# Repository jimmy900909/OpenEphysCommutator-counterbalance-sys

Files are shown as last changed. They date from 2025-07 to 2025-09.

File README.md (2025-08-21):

This is a wireless counterbalance system that can adjust the length of the cable automatically for OpenEphys commutator while conducting freely moving animal experiment  

#closed-loop Automatic Counterbalance animal experiment system 

#tension-free and biting-prevention for cable in the freely moving animal experiment

The toggling and dragging can seriously cause the artifacts to signal when doing a cable-connected behavior experiment on an awake and freely-moving animal. The automatic rotation commutator is widely used in labs and commercialized, however, to adjust the length of the cable is always depends on manual holding or passive counterbalance sys. As the hanged part would be bited by animal and the tension can constraint the movement, a active counterbalance system is needed for such animal experiment.

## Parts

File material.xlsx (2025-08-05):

Material | model number | amount | source | note
MCU | Arduino Nano | 1
Weight sensor | HX711 | 1 | https://www.amazon.de/Geekstory-Amplifier-Precision-Converter-Raspberry/dp/B0BVBBZG2V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
Loadcell | 100g | 1 | https://www.amazon.de/0%E2%80%91100G-Parallel-Electronic-Weighing-Precision/dp/B0BZ62BRWK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 | 300g or 500g can be alternative but the installation drill holes on the 3D print structure needs to be modified
Motor Driver | DRV8833 | 1 | https://www.amazon.de/-/en/Heevhas-DRV8833-Module-Controller-Printer/dp/B0DQZGP1J4
capacitor | 470muF | 1
capacitor | 100muF | 1
Gear Motor | FIT0483 | 1
Battery set | 6V | 1 |  | For MCU also Motor

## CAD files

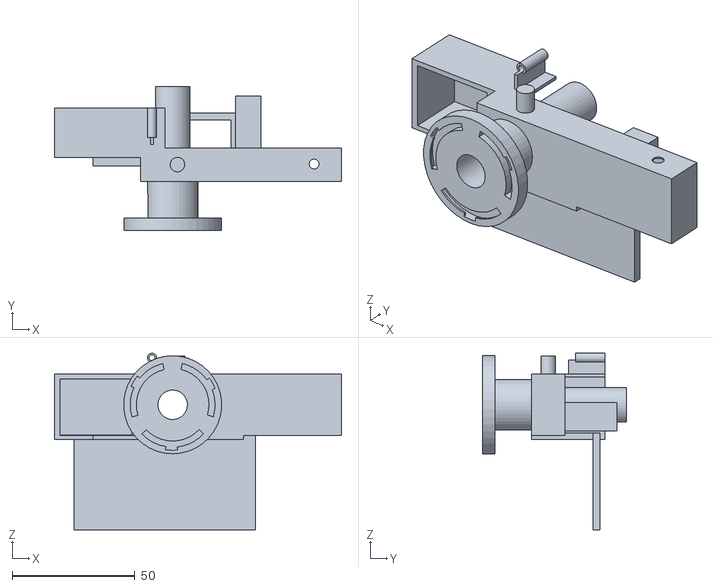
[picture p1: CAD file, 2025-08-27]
counterbalance/openephyscommutator/Holder_evas.STL
117.1 x 58.7 x 72.0

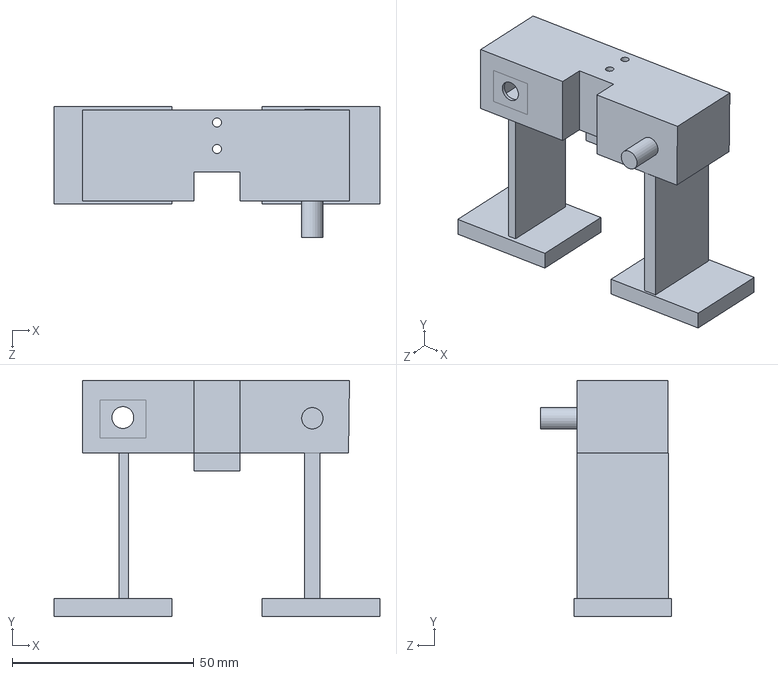
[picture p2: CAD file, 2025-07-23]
counterbalance/testing/TESTING frame.SLDPRT
89.6 x 65.0 x 35.9 mm

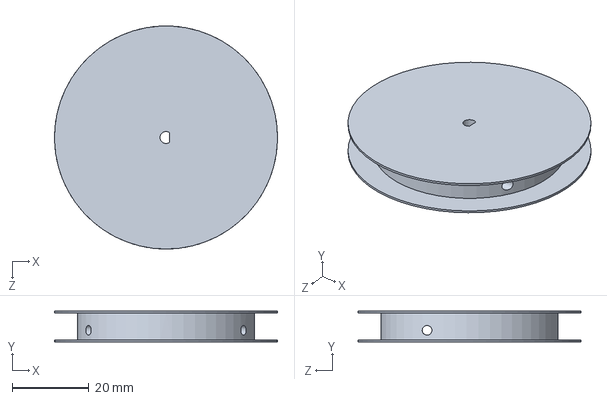
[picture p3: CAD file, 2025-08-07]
counterbalance/openephyscommutator/pulley_motor.SLDPRT
58.0 x 8.00 x 58.0 mm

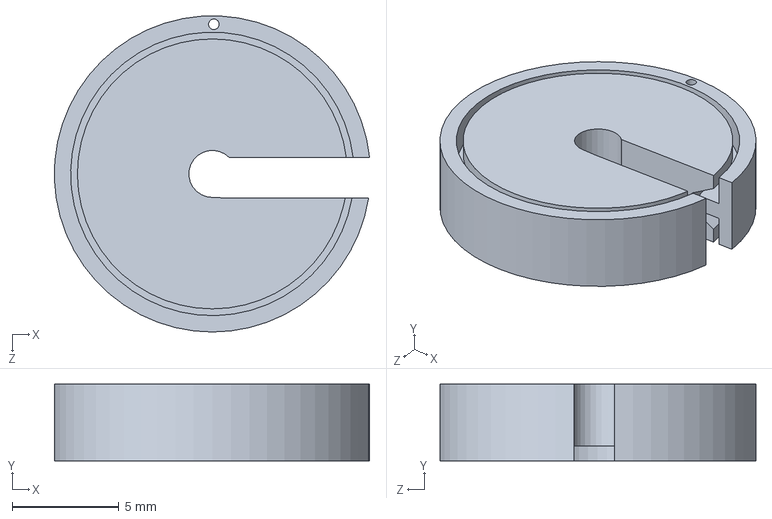
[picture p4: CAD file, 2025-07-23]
counterbalance/testing/bearing.SLDPRT
14.8 x 3.60 x 14.8 mm

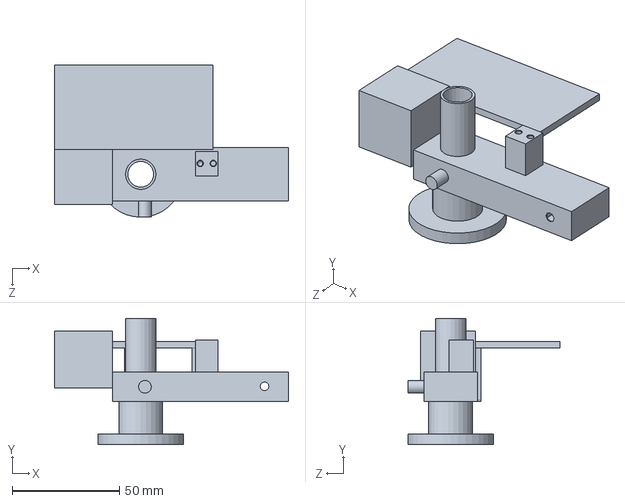
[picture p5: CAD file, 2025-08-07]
counterbalance/openephyscommutator/Holder_OE_v2.SLDPRT
109.1 x 58.7 x 71.0 mm

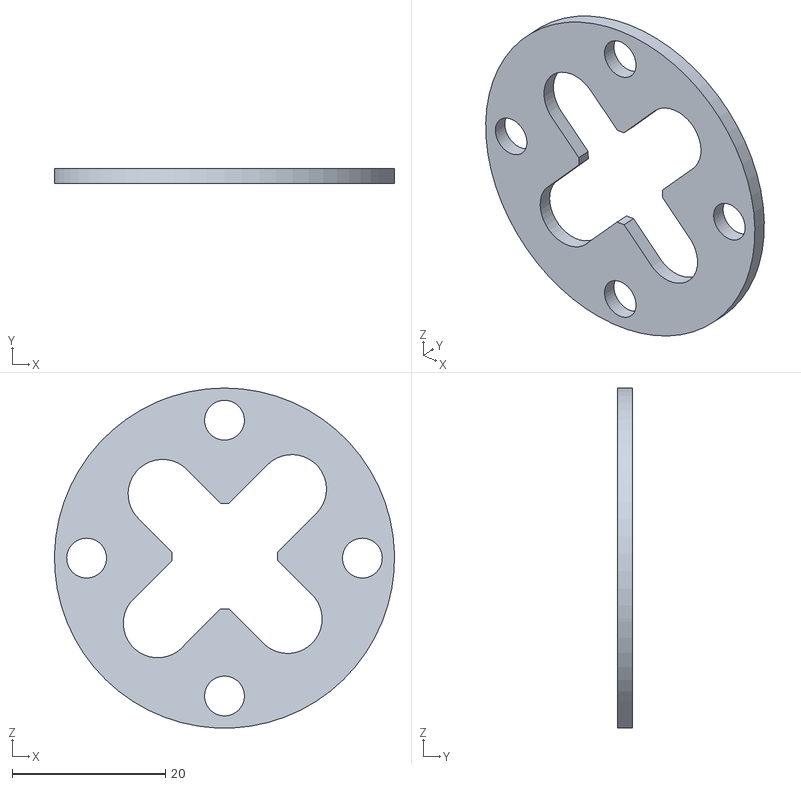
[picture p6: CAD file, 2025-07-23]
counterbalance/testing/attachplatform.STL
44.4 x 2.00 x 44.4

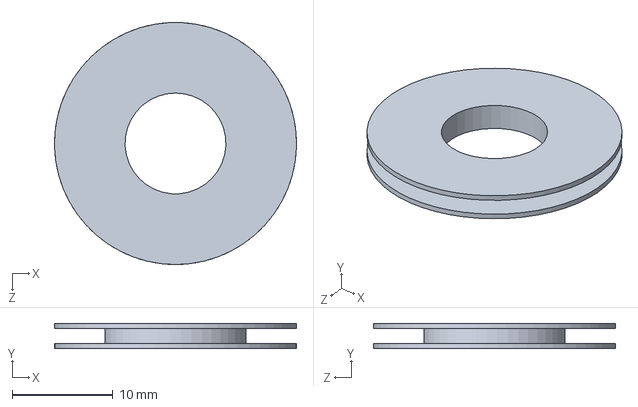
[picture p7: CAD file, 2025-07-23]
counterbalance/openephyscommutator/pulley_fixed.SLDPRT
24.0 x 2.50 x 24.0 mm

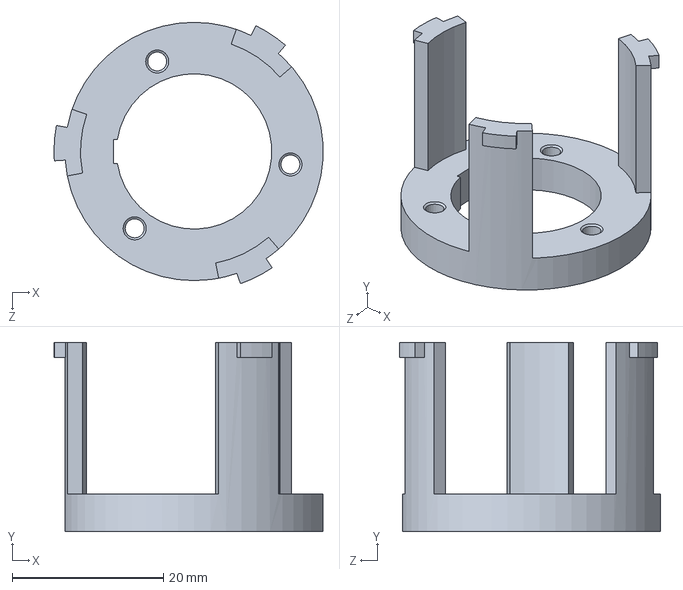
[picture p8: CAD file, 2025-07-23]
counterbalance/openephyscommutator/adaptor_OE.SLDPRT
35.5 x 25.0 x 34.5 mm

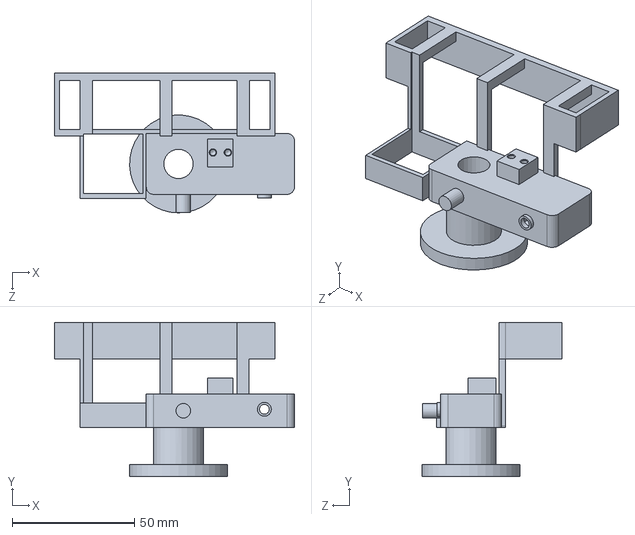
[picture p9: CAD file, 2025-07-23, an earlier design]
counterbalance/openephyscommutator/Holder_OE.SLDPRT
98.1 x 63.0 x 57.1 mm

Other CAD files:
counterbalance/openephyscommutator/Holder_OE.STL
counterbalance/openephyscommutator/Holder_OE_v2.STL
counterbalance/openephyscommutator/adaptor_OE.STL
counterbalance/openephyscommutator/pulley_fixed.STL
counterbalance/openephyscommutator/pulley_motor.STL
counterbalance/testing/TESTING frame.STL
counterbalance/testing/bearing.STL

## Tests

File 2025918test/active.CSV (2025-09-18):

time | T_fast_g | T_slow_g | v_line_mps | leash_m | pwm_state | enc_count | dTdt_gps
1758187201.288 | 0.0000 | 0.0000 | 0.000000 | 0.0000 | 60 | 0 | 0.00
1758187201.308 | 0.0000 | 0.0000 | 0.000000 | 0.0002 | 70 | 2 | 0.00
1758187201.328 | 0.0000 | 0.0000 | 0.088051 | 0.0010 | 70 | 11 | 0.00
1758187201.348 | 0.0000 | 0.0000 | 0.000000 | 0.0019 | 70 | 23 | 0.00
1758187201.368 | 0.0000 | 0.0000 | 0.088051 | 0.0033 | 70 | 38 | 0.00
1758187201.388 | -0.0040 | -0.0013 | 0.000000 | 0.0048 | 70 | 56 | 0.00
1758187201.408 | -0.0040 | -0.0013 | 0.088051 | 0.0064 | 70 | 73 | 0.00
1758187201.428 | -0.0040 | -0.0013 | 0.088051 | 0.0081 | 70 | 92 | 0.00
1758187201.448 | -0.0040 | -0.0013 | 0.088051 | 0.0097 | 70 | 110 | 0.00
1758187201.468 | -0.0040 | -0.0013 | 0.088051 | 0.0113 | 70 | 129 | 0.00
1758187201.488 | -0.0044 | -0.0021 | 0.088051 | 0.0129 | 70 | 146 | -0.00
1758187201.508 | -0.0044 | -0.0021 | 0.088051 | 0.0144 | 70 | 164 | -0.00
1758187201.528 | -0.0044 | -0.0021 | 0.088051 | 0.0158 | 70 | 181 | -0.00
1758187201.548 | -0.0044 | -0.0021 | 0.088051 | 0.0173 | 70 | 197 | -0.00
1758187201.568 | -0.0044 | -0.0021 | 0.088051 | 0.0188 | 70 | 213 | -0.00
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

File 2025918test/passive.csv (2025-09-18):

Timestamp | RawReading | Weight_g
2025-09-18 11:57:35.753 | 41840 | 0.00
2025-09-18 11:57:35.755 | 41747 | -0.01
2025-09-18 11:57:35.755 | 41789 | -0.00
2025-09-18 11:57:35.759 | 41779 | -0.01
2025-09-18 11:57:35.764 | 41789 | 0.00
2025-09-18 11:57:36.068 | 41740 | -0.02
2025-09-18 11:57:36.847 | 41819 | -0.00
2025-09-18 11:57:37.627 | 41724 | 0.00
2025-09-18 11:57:38.409 | 41811 | -0.01
2025-09-18 11:57:39.189 | 41776 | -0.00
2025-09-18 11:57:39.969 | 62621 | 6.28
2025-09-18 11:57:40.749 | 104551 | 15.10
2025-09-18 11:57:41.529 | 106632 | 17.36
2025-09-18 11:57:42.308 | 122982 | 19.24
2025-09-18 11:57:43.088 | 124694 | 19.62
2025-09-18 11:57:43.868 | 172800 | 31.02
2025-09-18 11:57:44.648 | 162331 | 28.33
2025-09-18 11:57:45.432 | 157970 | 27.94
2025-09-18 11:57:46.211 | 177289 | 31.47
2025-09-18 11:57:46.992 | 176594 | 32.62
2025-09-18 11:57:47.772 | 167508 | 27.82
2025-09-18 11:57:48.552 | 147660 | 23.36
2025-09-18 11:57:49.333 | 177326 | 32.94
2025-09-18 11:57:50.112 | 170128 | 30.60
2025-09-18 11:57:50.891 | 170732 | 31.23
2025-09-18 11:57:51.672 | 175176 | 32.32
2025-09-18 11:57:52.454 | 238303 | 42.79
2025-09-18 11:57:53.231 | 160631 | 23.22
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

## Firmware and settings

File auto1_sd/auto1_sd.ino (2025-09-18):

#include "HX711.h"
#include <SPI.h>
#include <SD.h>

// ---------------- Pins ----------------
// HX711
#define DOUT 4
#define CLK  5
// Motor
#define AIN1 6
#define AIN2 9
// Encoder pins
#define ENCODER_A 2
#define ENCODER_B 3
// SD module
const int SD_CS = 10;   // CS pin of SD card

// ---------------- HX711 ----------------
HX711 scale;
float calibration_factor = 4180;  // g
const float HX_RATE_HZ = 80.0f;   // soldering modified
unsigned long last_hx_ms = 0;
bool hx_updated = false;
bool have_prev_T = false;

// ---------------- Encoder → v_line ----------------
const float COUNTS_PER_METER = 11357.0f;
volatile long encoderCount = 0;
long lastCount = 0;
unsigned long lastVtMs = 0;
float v_line = 0.0f;         
float leash_len_m = 0.0f;

// ---------------- Motor / PWM ----------------
const int remotorSpeed = 65;   // retract PWM (upper bound)
int pwm_state = 0;
const int PWM_STEP_OUT = 120;   
const int PWM_STEP_IN  = 30;   
// retracting PWM
const int   BASE_RETRACT_PWM     = 45;     // base PWM
const int   MAX_RETRACT_PWM      = 70;     // Maximum PWM
const int   MIN_RETRACT_PWM      = 40;     // Minimum
const float KP_RETRACT_PWM_PER_G = 3.0f;   // gain per gram lower than lowerlimit

// loosening PWM
const int   BASE_PAYOUT_PWM   = 70;
const int   MAX_PAYOUT_PWM    = 190;
const float KP_PWM_PER_G      = 4.0f; // gain per gram after surpass upperlimit

// ---------------- Burst（instantpayout for strong drag） ----------------
const int BURST_PWM = 230;                     
const unsigned long BURST_MS = 150;            
unsigned long burst_until_ms = 0;

// ---------------- Landing impact give-way ----------------
const float IMPACT_DTDT_GPS = 90.0f;            
const float IMPACT_NEAR_UPPER_G = 0.8f;         
const unsigned long IMPACT_COAST_MS = 120;      
const int IMPACT_PAYOUT_PWM = 70;               
unsigned long impact_until_ms = 0;              

// No retracting after burst
const unsigned long POST_BURST_NO_RETRACT_MS = 600;     
unsigned long no_retract_until_ms = 0;

// ---------------- Smoothen tension ----------------
float T_fast_g = 0.0f;                
float T_slow_g = 0.0f;                
const float T_ALPHA_FAST = 0.8f;      // ★ bigger to be more sensitive 
const float T_ALPHA_SLOW = 0.25f;

// ---------------- threshold ----------------
float lower_limit = 11.7f;
float upper_limit = 19.5f;

float V_OUT_MIN = 0.004f;             
float T_MARGIN_G = 0.7f;
unsigned long ALLOW_PAYOUT_CONFIRM_MS = 5;  
bool allow_payout_latch = false;
unsigned long allow_payout_since_ms = 0;

// 鎖軸快速通道
const float V_EPS_LOCKED   = 0.003f;
const float T_LOCK_MARGING = 3.0f;
const float DTDT_LOCK_GPS  = 55.0f;
const unsigned long LOCK_CONFIRM_MS = 12;
bool locked_latch = false;
unsigned long locked_since_ms = 0;

// ---- dT/dt ----
float dTdt_raw = 0.0f;
float dTdt_gps = 0.0f;
float T_prev_for_dt = 0.0f;
const float DTDTA = 0.25f;

// Active-Coast
const int ASSIST_PWM = 140;               

// ---------------- Anti-chatter / Grace ----------------
bool inRetract = false;
unsigned long retract_start_ms;
long          retract_start_cnt;

const unsigned long MIN_RETRACT_MS  = 50;
const long          MIN_RETRACT_CNT = 10;

const unsigned long LOOSEN_GRACE_MS = 800;
unsigned long loosen_grace_until_ms = 0;

const float LOWER_HYST_G = 0.8f;

// ---------------- Loop time ----------------
const unsigned long LOOP_MS = 1;
unsigned long last_loop_ms = 0;

// ================= SD Logging =================
File logFile;
bool sd_ok = false;
unsigned long last_log_ms = 0;
const unsigned long LOG_INTERVAL_MS = 100; 
uint32_t log_lines_since_flush = 0;
const uint32_t FLUSH_EVERY = 20;           

// File check LOG00.CSV ~ LOG99.CSV
bool openLogFile() {
  char name[12] = "LOG00.CSV";
  for (int i = 0; i < 100; i++) {
    name[3] = '0' + (i/10);
    name[4] = '0' + (i%10);
    if (!SD.exists(name)) {
      logFile = SD.open(name, FILE_WRITE);
      if (logFile) {
        logFile.println(F("ms,T_fast_g,T_slow_g,v_line_mps,leash_m,pwm_state,enc_count,dTdt_gps"));
        logFile.flush();
        return true;
      } else {
        return false;
      }
    }
  }
  return false; 
}

void logLineCSV(unsigned long ms,
                float T_fast, float T_slow,
                float vline, float leash,
                int pwm, long enc, float dTdt) {
  if (!sd_ok || !logFile) return;
  logFile.print(ms);
  logFile.print(',');
  logFile.print(T_fast, 4);
  logFile.print(',');
  logFile.print(T_slow, 4);
  logFile.print(',');
  logFile.print(vline, 6);
  logFile.print(',');
  logFile.print(leash, 4);
  logFile.print(',');
  logFile.print(pwm);
  logFile.print(',');
  logFile.print(enc);
  logFile.print(',');
  logFile.println(dTdt, 2);

  if (++log_lines_since_flush >= FLUSH_EVERY) {
    log_lines_since_flush = 0;
    logFile.flush(); 
  }
}

// ---------------- helpers ----------------
inline void motorCoast() {
  digitalWrite(AIN1, LOW);
  digitalWrite(AIN2, LOW);
}

void driveMotor(int pwmSigned) {
  if (pwmSigned == 0) { motorCoast(); return; }
  if (pwmSigned > 0) {           
    int pwm = constrain(pwmSigned, 0, 255);
    digitalWrite(AIN1, LOW);
    analogWrite(AIN2, pwm);
  } else {                       
    int pwm = constrain(-pwmSigned, 0, 255);
    analogWrite(AIN1, pwm);
    digitalWrite(AIN2, LOW);
  }
}

int slewPWM(int target) {
  if (target == pwm_state) return pwm_state;
  if ((target > 0 && pwm_state >= 0) || (target < 0 && pwm_state <= 0)) {
    int step = (target > 0) ? PWM_STEP_IN : PWM_STEP_OUT;
    if (target > pwm_state) pwm_state = min(pwm_state + step, target);
    else                    pwm_state = max(pwm_state - step, target);
  } else {
    int step = (pwm_state > 0) ? PWM_STEP_IN : PWM_STEP_OUT;
    if (pwm_state > 0) pwm_state = max(0, pwm_state - step);
    else               pwm_state = min(0, pwm_state + step);
  }
  return pwm_state;
}

int map_constrain_float(float x, float in_min, float in_max, int out_min, int out_max) {
  if (in_max - in_min == 0) return out_min;
  float t = (x - in_min) / (in_max - in_min);
  if (t < 0) t = 0; if (t > 1) t = 1;
  float y = out_min + t * (out_max - out_min);
  return (int)y;
}

int applyDeadzone(int pwmSigned) {
  const int DEADZONE = 60;   
  if (pwmSigned == 0) return 0;
  if (pwmSigned > 0) {
    return max(pwmSigned, DEADZONE);
  } else {
    return min(pwmSigned, -DEADZONE);
  }
}

// ---------------- setup ----------------
void setup() {
  Serial.begin(9600);
  delay(300);

  pinMode(SD_CS, OUTPUT);
  digitalWrite(SD_CS, HIGH); 
  if (SD.begin(SD_CS)) {
    sd_ok = openLogFile();
    if (sd_ok) Serial.println(F("SD ready, logging started."));
    else       Serial.println(F("SD present but open file failed."));
  } else {
    Serial.println(F("SD init failed. Check wiring/level shifting."));
  }

  scale.begin(DOUT, CLK);
  delay(1500);
  if (!scale.is_ready()) { Serial.println("HX711 not found."); while (1); }
  scale.set_scale(calibration_factor);
  scale.tare();

  pinMode(AIN1, OUTPUT);
  pinMode(AIN2, OUTPUT);
  motorCoast();

  pinMode(ENCODER_A, INPUT_PULLUP);
  pinMode(ENCODER_B, INPUT_PULLUP);
  attachInterrupt(digitalPinToInterrupt(ENCODER_A), encoderISR, CHANGE);

  lastVtMs = millis();
  last_loop_ms = millis();
  last_hx_ms = millis();
  T_prev_for_dt = 0.0f;

  Serial.println("Ready ver5.instant-payout (no ramp, raw trigger).");
}

// ---------------- loop ----------------
void loop() {
  if (millis() - last_loop_ms < LOOP_MS) return;
  last_loop_ms = millis();

  // ---- 張力 ----
  hx_updated = false;
  float raw = 0.0f;
  if (scale.is_ready()) {
    raw = scale.get_units(1);
    T_fast_g = T_fast_g + T_ALPHA_FAST * (raw - T_fast_g);
    T_slow_g = T_slow_g + T_ALPHA_SLOW * (raw - T_slow_g);
    hx_updated = true;
  }
  float T_fast = -1*T_fast_g;
  float T_slow = -1*T_slow_g;

  unsigned long now = millis();
  unsigned long dt_ms = now - lastVtMs; if (dt_ms == 0) dt_ms = 1;
  lastVtMs = now;

  long cnt; noInterrupts(); cnt = encoderCount; interrupts();
  long dcount = cnt - lastCount; lastCount = cnt;

  float dt = dt_ms * 1e-3f;
  v_line = (COUNTS_PER_METER > 1e-6f) ? ((float)dcount / COUNTS_PER_METER) / dt : 0.0f;
  leash_len_m += v_line * dt;

  if (hx_updated) {
    float dtT_s = max(0.001f, (now - last_hx_ms) * 1e-3f);
    if (!have_prev_T) { dTdt_raw = 0.0f; have_prev_T = true; }
    else               dTdt_raw = (T_fast - T_prev_for_dt) / dtT_s;
    T_prev_for_dt = T_fast;
    last_hx_ms = now;
  }
  dTdt_gps = DTDTA * dTdt_raw + (1.0f - DTDTA) * dTdt_gps;

  // ---- 瞬間放線判斷 ----
  bool sudden_pull = ((raw > upper_limit + 15.0f) || (T_fast > upper_limit + 15.0f)) && (dTdt_gps > 70.0f);
  bool not_retracting = (v_line <= 0.0f);
  bool instant_payout = sudden_pull && not_retracting;

  if (instant_payout) {
    unsigned long new_until = now + BURST_MS;
    if (new_until > burst_until_ms) burst_until_ms = new_until;
    loosen_grace_until_ms = max(loosen_grace_until_ms, now + LOOSEN_GRACE_MS);
    no_retract_until_ms   = max(no_retract_until_ms,   now + POST_BURST_NO_RETRACT_MS);
    inRetract = false;
    Serial.println("00000");
    allow_payout_latch = true;
    allow_payout_since_ms = now;
  }

  // ---- 即時 burst ----
  if (now < burst_until_ms) {
    int steppedPWM = slewPWM(-BURST_PWM);
    steppedPWM = applyDeadzone(steppedPWM);
    driveMotor(steppedPWM);
    return;
  }

  // ---- 落地衝擊讓步 ----
  bool impact_detect = inRetract && ((dTdt_gps > IMPACT_DTDT_GPS) || (T_fast > upper_limit - IMPACT_NEAR_UPPER_G));
  if (impact_detect) {
    unsigned long new_until = now + IMPACT_COAST_MS;
    if (new_until > impact_until_ms) impact_until_ms = new_until;
  }
  if (now < impact_until_ms) {
    int targetPWM = 0;
    if (T_fast > upper_limit - 0.3f) {
      targetPWM = -IMPACT_PAYOUT_PWM; 
    }
    int steppedPWM = slewPWM(targetPWM);
    steppedPWM = applyDeadzone(steppedPWM);
    driveMotor(steppedPWM);
    inRetract = false;
    return;
  }

  // ---- 放線許可 ----
  bool line_out = (v_line < -V_OUT_MIN);
  bool high_T   = (T_fast > (upper_limit + T_MARGIN_G));
  if (high_T) {
    if (!allow_payout_latch) { allow_payout_latch = true; allow_payout_since_ms = now; }
  } else {
    allow_payout_latch = false;
  }
  bool allow_payout_dir = allow_payout_latch && (now - allow_payout_since_ms >= ALLOW_PAYOUT_CONFIRM_MS);

  bool spool_static = (fabs(v_line) < 0.003f);
  bool locked_trig  = spool_static && (T_fast > upper_limit + T_LOCK_MARGING) && (dTdt_gps > DTDT_LOCK_GPS);
  if (locked_trig) {
    if (!locked_latch) { locked_latch = true; locked_since_ms = now; }
  } else {
    locked_latch = false;
  }
  bool allow_payout_locked = locked_latch && (now - locked_since_ms >= LOCK_CONFIRM_MS);
  bool allow_payout = allow_payout_dir || allow_payout_locked;

  // ---- 主邏輯 ----
  int targetPWM = 0;
  if (T_fast > upper_limit) {
    if (allow_payout) {
      float over_g = T_fast - upper_limit;
      int pwm = (int)(BASE_PAYOUT_PWM + KP_PWM_PER_G * over_g);
      pwm = constrain(pwm, BASE_PAYOUT_PWM, MAX_PAYOUT_PWM);
      targetPWM = -pwm;
      loosen_grace_until_ms = now + LOOSEN_GRACE_MS;
      no_retract_until_ms   = max(no_retract_until_ms, now + POST_BURST_NO_RETRACT_MS);
      inRetract = false;
    } else {
      targetPWM = 0;
    }
  } else if (T_slow < (lower_limit - LOWER_HYST_G)
             && now >= loosen_grace_until_ms
             && now >= no_retract_until_ms) {
    if (!inRetract) { inRetract = true; retract_start_ms = now; retract_start_cnt = cnt; }
  float under_g = (lower_limit - T_slow);
  int pwm = (int)(BASE_RETRACT_PWM + KP_RETRACT_PWM_PER_G * under_g);
  pwm = constrain(pwm, MIN_RETRACT_PWM, MAX_RETRACT_PWM);
  targetPWM = +pwm;
  } else if (T_fast < lower_limit) {
    targetPWM = 0;
  } else {
    if (inRetract) {
      if (T_fast > upper_limit - 0.8f) { targetPWM = 0; inRetract = false; }
      else {
        bool time_ok = (now - retract_start_ms) >= MIN_RETRACT_MS;
        bool cnt_ok  = (labs(cnt - retract_start_cnt) >= MIN_RETRACT_CNT);
        bool window_ok = (now >= loosen_grace_until_ms) && (now >= no_retract_until_ms);
        if (time_ok && cnt_ok && window_ok) { targetPWM = 0; inRetract = false; }
        else {
          int cap = map_constrain_float(T_fast, lower_limit - 1.0f, upper_limit - 0.5f, remotorSpeed, 10);
          cap = constrain(cap, 10, remotorSpeed);
          targetPWM = +cap;
        }
        if (!window_ok) { targetPWM = 0; inRetract = false; }
      }
    } else {
      targetPWM = 0;
    }
  }

  bool nearly_upper = (T_fast >= (upper_limit - 0.3f));
  if (targetPWM == 0 && nearly_upper && spool_static) {
    targetPWM = -ASSIST_PWM;
  }

  if (now < loosen_grace_until_ms || now < no_retract_until_ms) {
    if (targetPWM > 0) { targetPWM = 0; }
  }

  int steppedPWM = slewPWM(targetPWM);
  steppedPWM = applyDeadzone(steppedPWM);
  driveMotor(steppedPWM);

  if ((millis() % 100) < LOOP_MS) {
    Serial.print("T_fast(g)="); Serial.print(T_fast, 2);
    Serial.print("  T_slow(g)="); Serial.print(T_slow, 2);
    Serial.print("  v_line(m/s)="); Serial.print(v_line, 3);
    Serial.print("  PWM="); Serial.print(steppedPWM);
    Serial.println();
  }

  if (sd_ok && (now - last_log_ms >= LOG_INTERVAL_MS)) {
    last_log_ms = now;
    long enc_now; noInterrupts(); enc_now = encoderCount; interrupts();
    logLineCSV(now, T_fast, T_slow, v_line, leash_len_m, steppedPWM, enc_now, dTdt_gps);
  }
}

// ---------------- ISR ----------------
void encoderISR() {
  int a = digitalRead(ENCODER_A);
  int b = digitalRead(ENCODER_B);
  if (a == b) encoderCount++;
  else        encoderCount--;
}

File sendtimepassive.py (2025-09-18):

import tkinter as tk
from tkinter import ttk, filedialog, messagebox
import serial
import threading
import time
import csv
import serial.tools.list_ports
from datetime import datetime  # ✅ 新增

class HX711Logger:
    def __init__(self, root):
        self.root = root
        self.root.title("HX711 Loadcell Logger")
        self.root.geometry("400x250")

        # 狀態變數
        self.ser = None
        self.is_logging = False
        self.thread = None
        self.output_file = "tension_log.csv"

        # --- UI 元件 ---
        # COM Port 選擇
        tk.Label(root, text="COM Port:").pack(pady=5)
        self.combobox_port = ttk.Combobox(root, values=self.get_serial_ports(), state="readonly")
        self.combobox_port.pack()

        # Baudrate
        tk.Label(root, text="Baudrate:").pack(pady=5)
        self.baud_entry = tk.Entry(root)
        self.baud_entry.insert(0, "9600")
        self.baud_entry.pack()

        # 當前數據
        self.label_data = tk.Label(root, text="Current Data: ---", font=("Arial", 14))
        self.label_data.pack(pady=10)

        # 按鈕
        self.start_btn = tk.Button(root, text="Start Logging", command=self.start_logging, bg="green", fg="white")
        self.start_btn.pack(pady=5)

        self.stop_btn = tk.Button(root, text="Stop Logging", command=self.stop_logging, bg="red", fg="white", state=tk.DISABLED)
        self.stop_btn.pack(pady=5)

    def get_serial_ports(self):
        ports = serial.tools.list_ports.comports()
        return [p.device for p in ports]

    def start_logging(self):
        port = self.combobox_port.get()
        baud = self.baud_entry.get()

        if not port:
            messagebox.showerror("Error", "請選擇 COM Port")
            return

        try:
            baud = int(baud)
        except ValueError:
            messagebox.showerror("Error", "Baudrate 必須是數字")
            return

        try:
            self.ser = serial.Serial(port, baud, timeout=1)
        except Exception as e:
            messagebox.showerror("Error", f"無法開啟序列埠: {e}")
            return

        # 選擇輸出檔案
        self.output_file = filedialog.asksaveasfilename(defaultextension=".csv",
                                                        filetypes=[("CSV files", "*.csv")],
                                                        title="選擇輸出檔案")
        if not self.output_file:
            self.ser.close()
            return

        self.is_logging = True
        self.start_btn.config(state=tk.DISABLED)
        self.stop_btn.config(state=tk.NORMAL)

        self.thread = threading.Thread(target=self.log_data)
        self.thread.daemon = True
        self.thread.start()

    def log_data(self):
        with open(self.output_file, mode="w", newline="") as file:
            writer = csv.writer(file)
            writer.writerow(["Timestamp", "RawReading", "Weight_g"])  # 標頭

            raw = "---"  # 避免還沒讀到 Raw 時就寫入

            while self.is_logging:
                try:
                    line = self.ser.readline().decode("utf-8").strip()
                    if line:
                        if line.startswith("Raw reading:"):
                            raw = line.split(":")[1].strip()
                        elif line.startswith("Weight:"):
                            weight = line.split(":")[1].strip().split()[0]
                            # ✅ 毫秒時間戳記
                            timestamp = datetime.now().strftime("%Y-%m-%d %H:%M:%S.%f")[:-3]
                            writer.writerow([timestamp, raw, weight])
                            file.flush()  # ✅ 即時寫入
                            self.label_data.config(text=f"Current Data: {weight} g")
                except Exception as e:
                    print("Error reading serial:", e)
                    break
        self.ser.close()

    def stop_logging(self):
        self.is_logging = False
        self.start_btn.config(state=tk.NORMAL)
        self.stop_btn.config(state=tk.DISABLED)
        messagebox.showinfo("Info", f"紀錄完成，已存檔：{self.output_file}")

if __name__ == "__main__":
    root = tk.Tk()
    app = HX711Logger(root)
    root.mainloop()

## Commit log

2025-07-23 Add motorization as a regulaer folder
    [GEARbase.SLDPRT, GEARconnected.SLDPRT, GEARconnected.STL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]
2025-08-04 version 1.1
    [GEARbase.SLDPRT, GEARconnected.SLDPRT, GEARconnected.STL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]
2025-08-04 For OEcommutator
    [GEARbase.SLDPRT, Holder_OE.SLDPRT, Holder_OE.STL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]
2025-08-05 material updated
    [material.xlsx]
2025-08-06 V1.2 bool emg and 80Hz
2025-08-07 V2.1 enhance version
    [Holder_OE_v2.SLDPRT, Holder_OE_v2.STL, pulley_motor.SLDPRT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]
2025-09-15 stable_suc version
    [0911_FIRST_Countnocom.CSV]
2025-09-18 first recording
    [active.CSV, passive.csv]
